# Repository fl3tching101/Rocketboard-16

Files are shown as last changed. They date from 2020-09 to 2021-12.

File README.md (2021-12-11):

# Rocketboard-16
 16 key RGB backlit macro board/numpad with two EC11 rotary encoder switches and a 128x64 OLED display
 
 <p align="center">
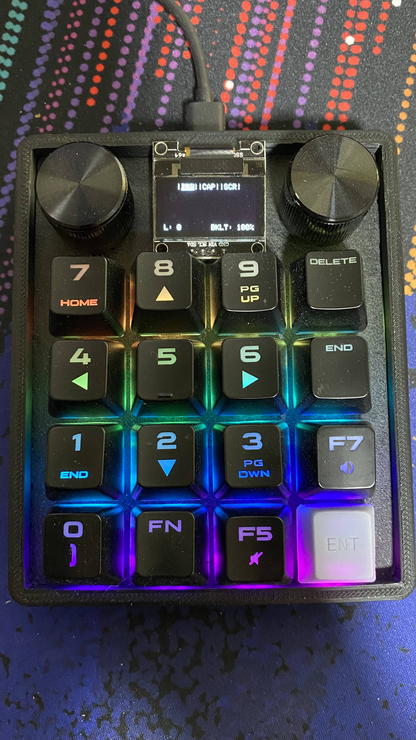
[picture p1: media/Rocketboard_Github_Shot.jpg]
 
 </p>

In addition to running [QMK](https://qmk.fm/) the Rocketboard 16 is compatible with [VIA](https://caniusevia.com/) for quick and easy configuration.
<p align="center">
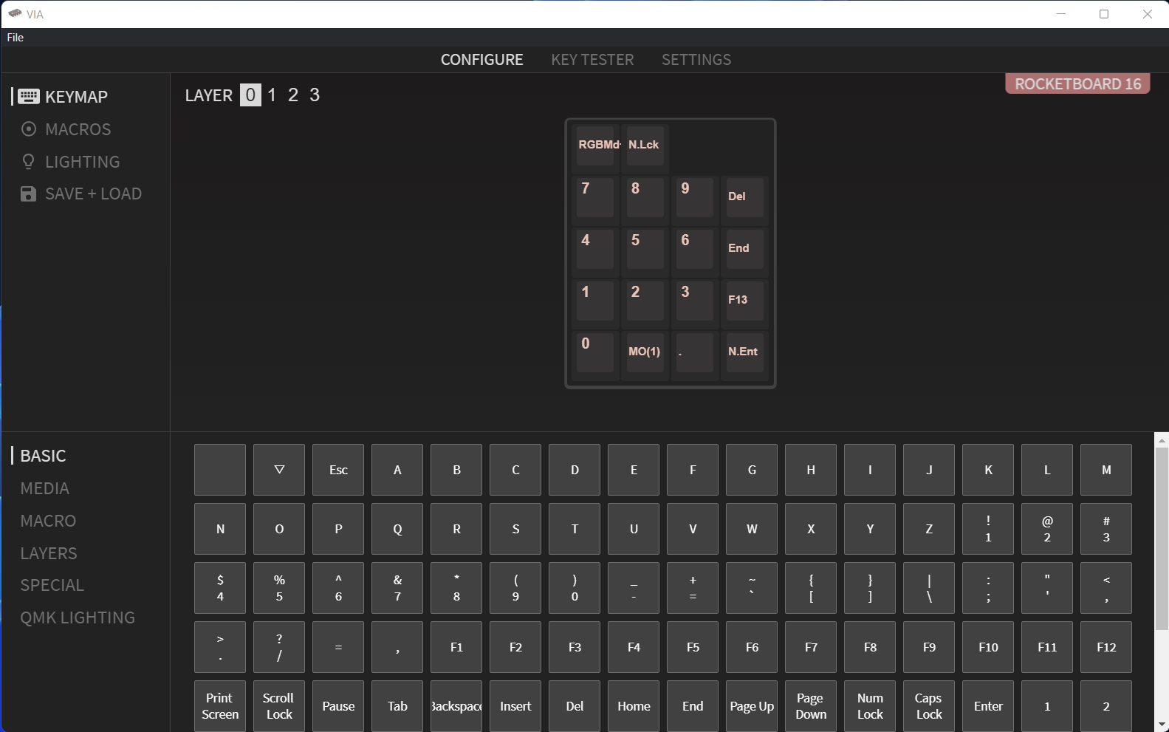
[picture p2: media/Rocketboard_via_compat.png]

</p>
 
The firmware is open source and integrated with the QMK project, it can be found [here](https://github.com/qmk/qmk_firmware/tree/master/keyboards/rocketboard_16).

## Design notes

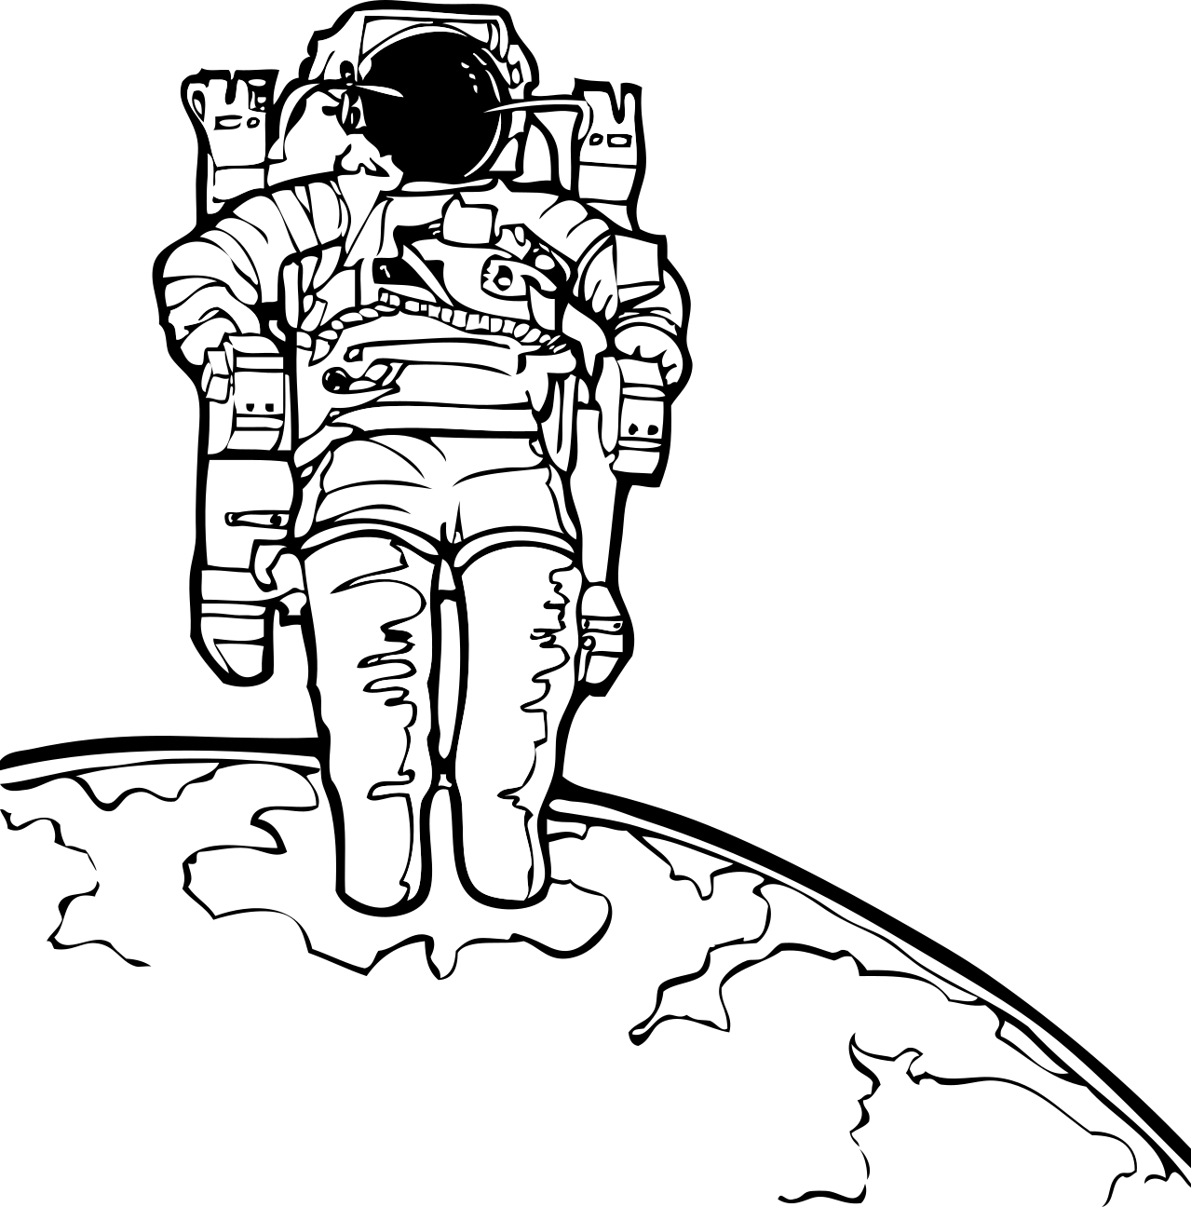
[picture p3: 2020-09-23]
graphics/spacewalk.png

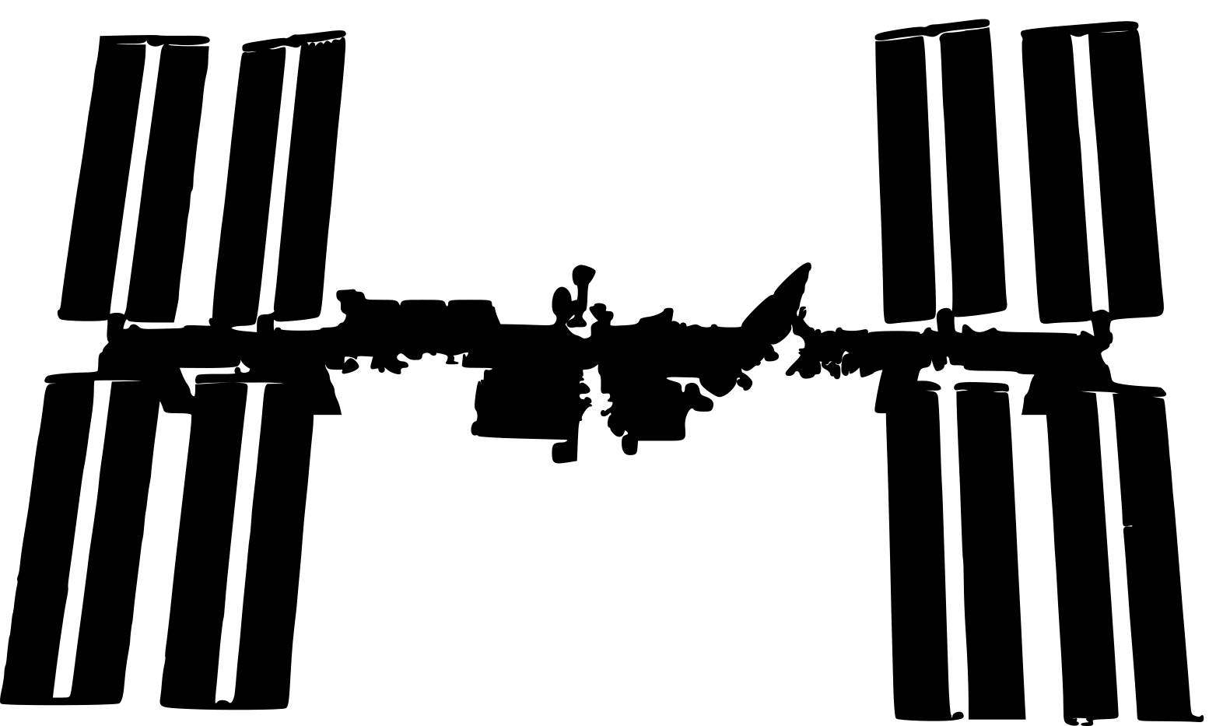
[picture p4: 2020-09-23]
graphics/ISS.png

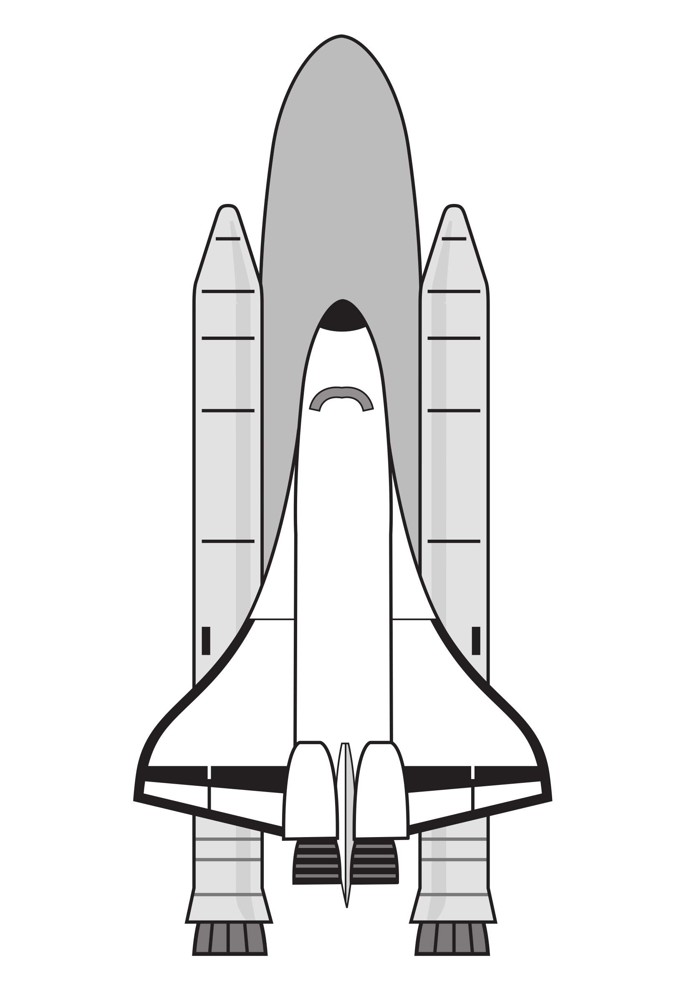
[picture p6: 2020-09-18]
graphics/space_shuttle.png

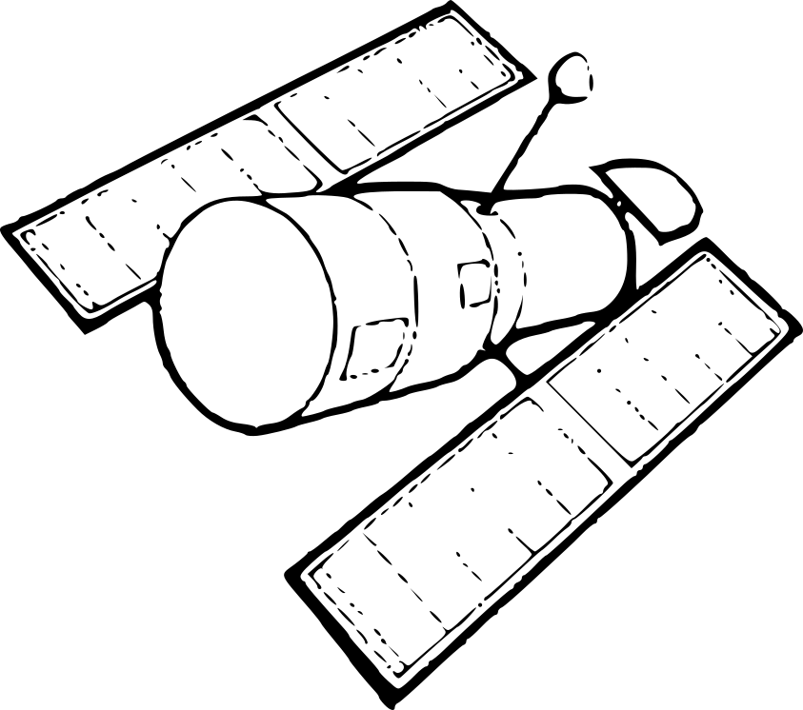
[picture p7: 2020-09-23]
graphics/Hubble_space_telescope.png

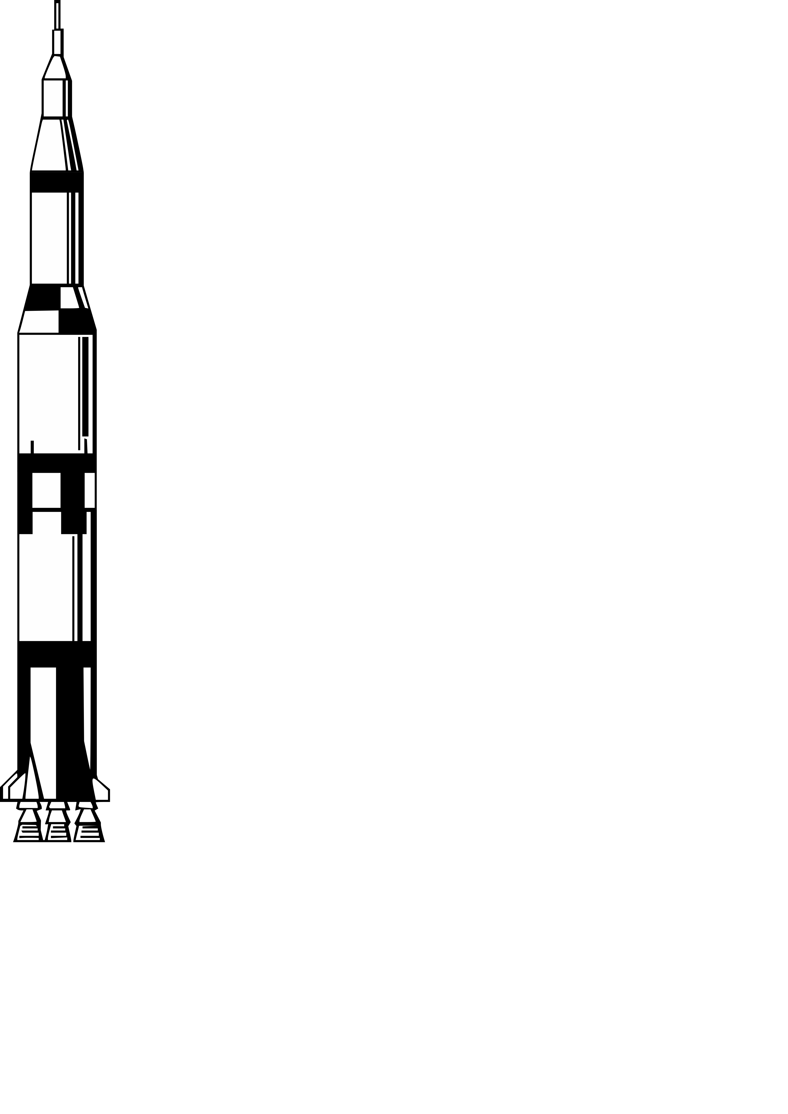
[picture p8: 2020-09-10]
graphics/saturn_v_simplified.png

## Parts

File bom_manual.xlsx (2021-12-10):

Qty | Reference(s) | Value | Footprint | MPN | Vender | Vender Part # | Manufacturer | DNP | Cost | Board Cost | Notes
2 | C1, C2 | 20p | Capacitor_SMD:C_0603_1608Metric | CL10C200JB8NNNC | JLCPCB | C1648 | Samsung Electro-Mechanics |  | $0.0085 | $0.0170
2 | C3, C12 | 10p | Capacitor_SMD:C_0603_1608Metric | CL10C100JB8NNNC | JLCPCB | C1634 | Samsung Electro-Mechanics |  | $0.0083 | $0.0166 | Only to be loaded on prototypes unless a use is found for the LSE (RTC) oscillator
27 | C4, C5, C6, C7, C8, C9, C14, C15, C16, C17, C18, C19, C20, C21, C22, C23, C24, C25, C26, C27, C28, C29, C30, C32, C33, C34, C35 | 0.1u | Capacitor_SMD:C_0603_1608Metric | CC0603KRX7R9BB104 | JLCPCB | C14663 | YAGEO |  | $0.0068 | $0.1836
1 | C10 | 1u | Capacitor_Tantalum_SMD:CP_EIA-3216-10_Kemet-I | CA45-A-16V-1uF-K | JLCPCB | C140386 | Shenzhen Zhenhua XinYun Elec |  | $0.0716 | $0.0716 | POLARIZED!!!
1 | C11 | 3.3u | Capacitor_SMD:C_0603_1608Metric | CL10A335KP8NNNC | JLCPCB | C51412 | Samsung Electro-Mechanics |  | $0.0170 | $0.0170 | Only 10v, careful!
1 | C13 | 10u | Capacitor_Tantalum_SMD:CP_EIA-3216-10_Kemet-I | TAJA106K016RNJ | JLCPCB | C7171 | AVX |  | $0.1549 | $0.1549
1 | C31 | 1u | Capacitor_SMD:C_0603_1608Metric | CL10A105KB8NNNC | JLCPCB | C15849 | Samsung Electro-Mechanics |  | $0.0129 | $0.0129
1 | C36 | 10u | Capacitor_SMD:C_0603_1608Metric | CL10A106MA8NRNC | LCSC | C96446 | Samsung Electro-Mechanics | Yes | $0.0334 | $0.0334
19 | D1, D2, D3, D4, D5, D6, D7, D8, D9, D10, D11, D12, D13, D14, D15, D16, D17, D18, D19 | D | Diode_SMD:D_SOD-123 | 1N4148W | JLCPCB | C81598 | Semtech |  | $0.0140 | $0.2660
16 | D20, D21, D22, D23, D24, D25, D26, D27, D28, D29, D30, D31, D32, D33, D34, D35 | SK6812MINI-E | seth-keyboard:DUMMY_SK6812MINI-E | YS-SK6812MINI-E | AliExpress |  | Yushakobo | Yes | $0.1049 | $1.6784 | Cannot find anywhere but AliExpress, will have to be hand soldered for the time being
4 | H1, H2, H3, H4 | Mount | MountingHole:MountingHole_3.2mm_M3 |  |  |  |  | Yes |  | $0.0000 | Nothing to be loaded
1 | H5 | Graphic | seth-logo:saturn_v_simplified |  |  |  |  |  |  | $0.0000
1 | H6 | Board Info | seth-logo:board-title |  |  |  |  |  |  | $0.0000
1 | H7 | Graphic | seth-logo:lunar_module |  |  |  |  |  |  | $0.0000
1 | H8 | Board Info | seth-logo:text |  |  |  |  |  |  | $0.0000
1 | H9 | Graphic | seth-logo:space_shuttle |  |  |  |  |  |  | $0.0000
1 | H10 | Graphic | seth-logo:iss |  |  |  |  |  |  | $0.0000
1 | H11 | Graphic | seth-logo:spacewalk |  |  |  |  |  |  | $0.0000
1 | H12 | Graphic | seth-logo:hubble_space_telescope |  |  |  |  |  |  | $0.0000
1 | J1 | SWD | Connector_PinHeader_2.54mm:PinHeader_1x04_P2.54mm_Vertical |  |  |  |  | Yes |  | $0.0000 | Will only be loaded for debugging purposes
1 | JP1 | BOOT1_JMP | Jumper:SolderJumper-3_P1.3mm_Open_Pad1.0x1.5mm |  |  |  |  | Yes |  | $0.0000 | Is only a footprint
1 | JP2 | BOOT0_JMP | Jumper:SolderJumper-3_P1.3mm_Open_Pad1.0x1.5mm |  |  |  |  | Yes |  | $0.0000 | Is only a footprint
16 | K1, K2, K3, K4, K5, K6, K7, K8, K9, K10, K11, K12, K13, K14, K15, K16 | MX_RGB | seth-keyboard:MX_KEYSWITCH_RGB_2D |  |  |  |  | Yes |  | $0.0000 | Footprint only, user will load own switch
1 | P1 | USB_C_Plug_USB2.0 | Connector_USB:USB_C_Receptacle_Palconn_UTC16-G | MC-311D | LCSC | C136423 | SOFNG | Yes | $0.8450 | $0.8450 | Not carried by JLCPCB - mounting pins may not be long enough for 1.6mm board!
1 | Q1 | BSS138 | Package_TO_SOT_SMD:SOT-23 | BSS138 | LCSC | C489349 | KEXIN |  | $0.0173 | $0.0173
2 | R1, R2 | 20 | Resistor_SMD:R_0603_1608Metric | 0603WAF200JT5E | JLCPCB | C22950 | Uniroyal Elec |  | $0.0016 | $0.0032
15 | R3, R8, R9, R10, R11, R12, R13, R14, R15, R16, R17, R18, R19, R20, R21 | 10k | Resistor_SMD:R_0603_1608Metric | 0603WAF1002T5E | JLCPCB | C25804 | Uniroyal Elec |  | $0.0020 | $0.0300
2 | R4, R5 | 5.1k | Resistor_SMD:R_0603_1608Metric | 0603WAF5101T5E | JLCPCB | C23186 | Uniroyal Elec |  | $0.0019 | $0.0038
1 | R6 | 1.5k | Resistor_SMD:R_0603_1608Metric | 0603WAF1501T5E | JLCPCB | C22843 | Uniroyal Elec |  | $0.0018 | $0.0018
1 | R7 | 1k | Resistor_SMD:R_0603_1608Metric | 0603WAF1001T5E | JLCPCB | C21190 | Uniroyal Elec |  | $0.0021 | $0.0021
1 | SW1 | SW_Push | Button_Switch_SMD:SW_Push_1P1T_NO_6x6mm_H9.5mm | TS-1187A-C-C-B | JLCPCB | C318889 | XKB Enterprise |  | $0.0348 | $0.0348
1 | SW2 | Rotary 1 | seth-buttons:RotaryEncoder_Alps_EC11E-Switch_Vertical_H20mm_CircularMountingHoles | EC11E1534408 | LCSC | C278348 | ALPS Electric | Yes | $1.9433 | $1.9433
1 | SW3 | Rotary 2 | seth-buttons:RotaryEncoder_Alps_EC11E-Switch_Vertical_H20mm_CircularMountingHoles | EC11E1534408 | LCSC | C278348 | ALPS Electric | Yes | $1.9433 | $1.9433
1 | U1 | STM32F103C8T6 | Package_QFP:LQFP-48_7x7mm_P0.5mm | STM32F103C8T6 | JLCPCB | C8734 | STMicroelectronics |  | $1.4413 | $1.4413
1 | U2 | AMS1117-3.3 | Package_TO_SOT_SMD:SOT-223-3_TabPin2 | AMS1117-3.3 | JLCPCB | C6186 | Advanced Monolithic Systems |  | $0.1240 | $0.1240
1 | U3 | USBLC6-2SC6 | Package_TO_SOT_SMD:SOT-23-6 | USBLC6-2SC6 | JLCPCB | C7519 | STMicroelectronics |  | $0.0915 | $0.0915
1 | U4 | SSD1306_128x64 | Connector_PinHeader_2.54mm:PinHeader_1x04_P2.54mm_Vertical | MTF185-104SY1 | LCSC | C358718 | MINTRON | Yes | $0.0550 | $0.0550
1 | X1 | 8 MHz | Crystal:Crystal_SMD_5032-4Pin_5.0x3.2mm | X50328MSB4SI | JLCPCB | C157341 | Yangxing Tech |  | $0.2187 | $0.2187
1 | Y1 | 32.768 kHz | Crystal:Crystal_SMD_3215-2Pin_3.2x1.5mm | Q13FC1350000200 | JLCPCB | C48615 | Seiko Epson |  | $0.2336 | $0.2336 | Only to be loaded on prototypes unless a use is found for the LSE (RTC) oscillator
 |  |  |  |  |  |  | Unique parts (loaded) count: |  |  | JLCPCB Cost:
 |  |  |  |  |  |  | 28 |  |  | $2.9417
 |  |  |  |  |  |  | Number of loaded SMD parts: |  |  | Other Cost:
 |  |  |  |  |  |  | 90 |  |  | $6.4984
 |  |  |  |  |  |  | Number of parts: |  |  | Total Cost:
 |  |  |  |  |  |  | 134 |  |  | $9.4401
 | Alternates:
1 | U2 | AMS1117-3.3 | Package_TO_SOT_SMD:SOT-223-3_TabPin2 | AMS1117-3.3 | JLCPCB | C347222 | UMW(Youtai Semiconductor Co., Ltd.) |  | $0.1240 | $0.1240
1 | Y1 | 32.768 kHz | Crystal:Crystal_SMD_3215-2Pin_3.2x1.5mm | X1A000141000100 | JLCPCB | C94674 | Seiko Epson |  | $0.2336 | $0.2336 | Only to be loaded on prototypes unless a use is found for the LSE (RTC) oscillator
27 | C4, C5, C6, C7, C8, C9, C14, C15, C16, C17, C18, C19, C20, C21, C22, C23, C24, C25, C26, C27, C28, C29, C30, C32, C33, C34, C35 | 0.1u | Capacitor_SMD:C_0603_1608Metric | FN18F104Z500PSG | JLCPCB | C497032 | PSA(Prosperity Dielectrics) |  | $0.0030 | $0.0813

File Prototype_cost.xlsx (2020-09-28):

Vender | Description | Cost | Notes
Aliexpress | SK6812Mini-E RGB LEDs x 100 | $11.2800 | Not able to find these anywhere else, shipping is slow Aliexpress value shipping
u/tonsoffun | Mill-Max 0305-2-15-80-47-80-10 x 200 | $25.0000 | Cheaper than Mouser order, $18 + $7 shipping
JLCPCB | PCB + Stencil | $34.9100 | Went with FedEx International for about $10 less shipping
LCSC | Parts (see LCSC BOM) | $59.8500 | Saved $15 on shipping with a first order coupon
Amazon | SSD1306 128x64 OLED Display x 6 | $33.3200 | Bought 4 blue PCBs and 2 black PCBs, both white pixels
 | Rotary encoder knobs
 | Total: | $164.3600

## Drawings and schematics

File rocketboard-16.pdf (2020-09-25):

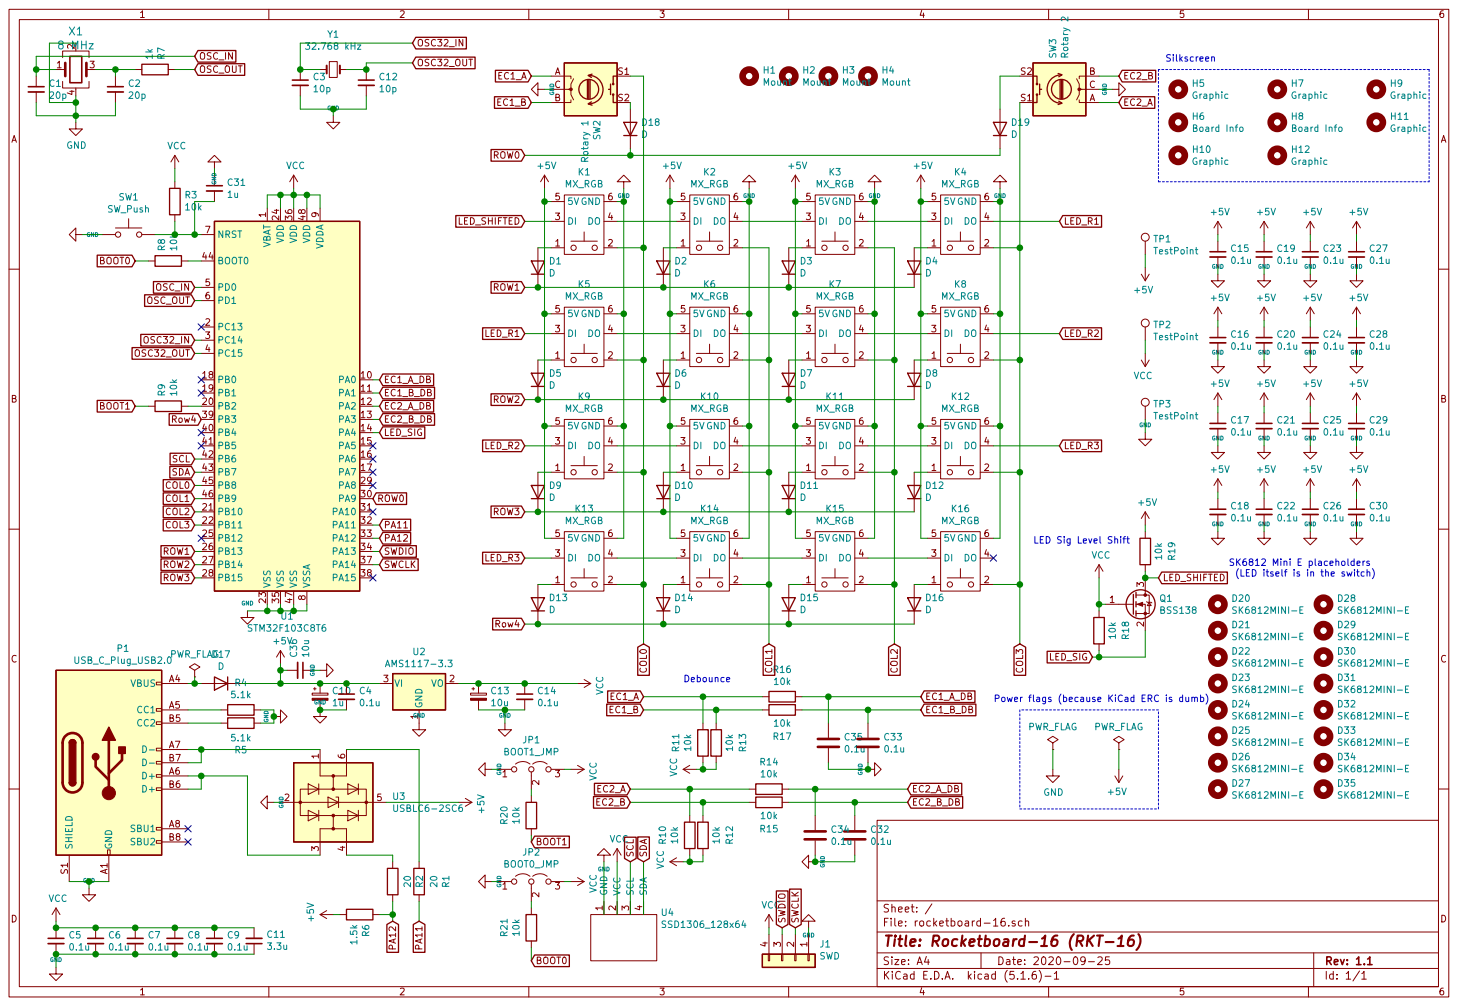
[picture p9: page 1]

1 VDD 24 VDD 36 VDD 48 VDDA

9 VSS 23 VSS 35 VSS 47 VSSA

Id: 1/1 Title: Rocketboard-16 (RKT-16) File: rocketboard-16.sch Sheet: / R810k

LED Sig Level Shift

SK6812 Mini E placeholders
(LED itself is in the switch)

4U4SSD1306_128x64 D22 SK6812MINI-E D21 SK6812MINI-E GND GND VCC VCC

Power flags (because KiCad ERC is dumb) Debounce

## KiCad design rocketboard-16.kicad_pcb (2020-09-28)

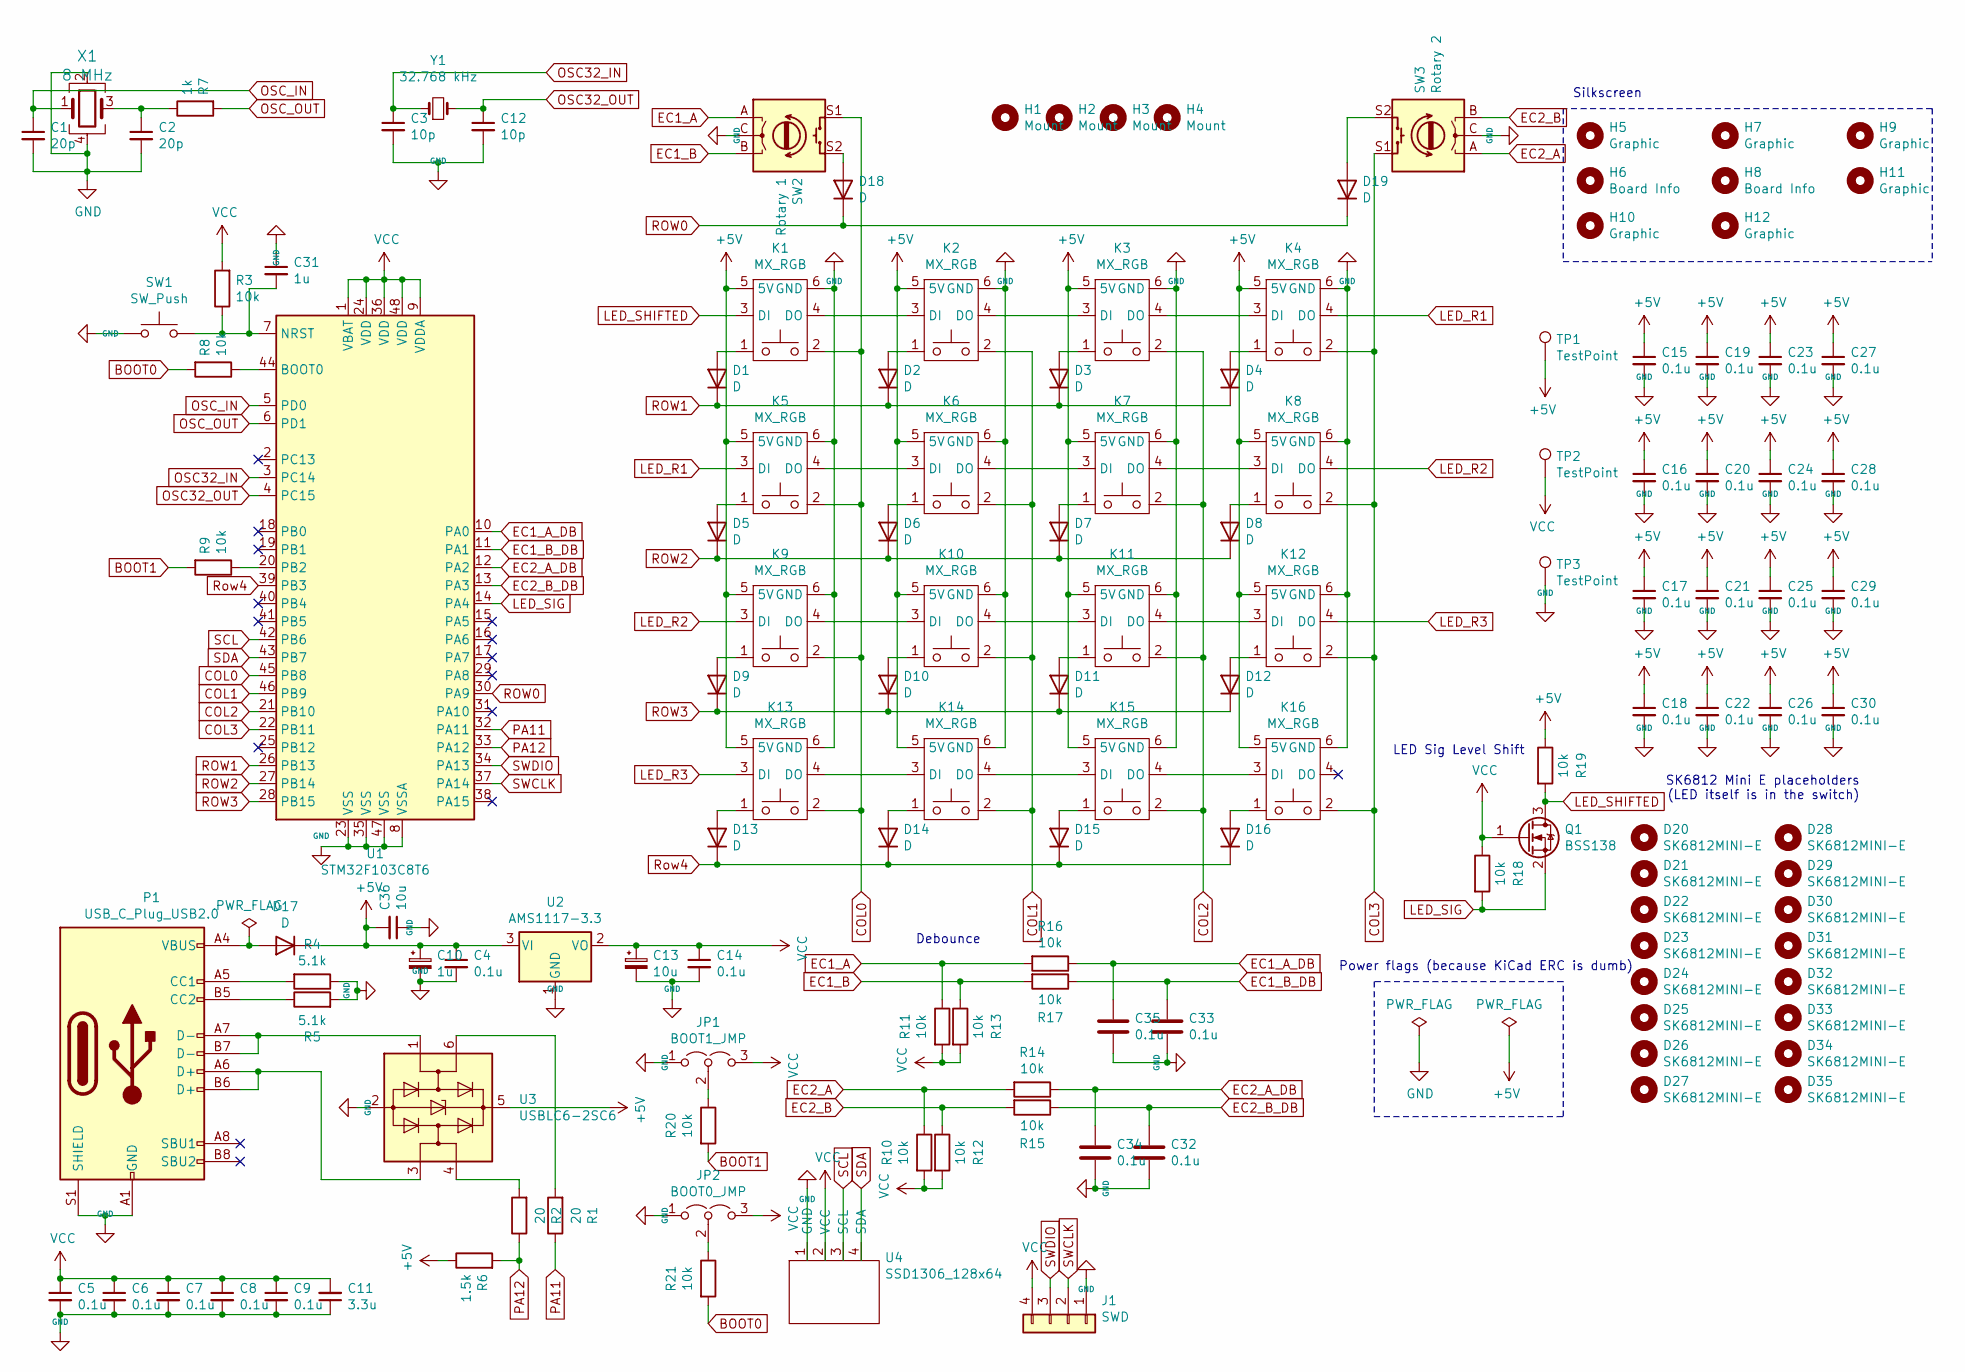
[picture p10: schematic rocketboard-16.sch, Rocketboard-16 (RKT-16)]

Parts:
C1, C2: 20p; C_0603_1608Metric
C3, C12: 10p; C_0603_1608Metric
C4, C5, C6, C7, C8, C9, C14, C15, C16, C17, C18, C19, C20, C21, C22, C23, C24, C25, C26, C27, C28, C29, C30, C32, C33, C34, C35: 0.1u; C_0603_1608Metric
C10: 1u; CP_EIA-3216-10_Kemet-I
C11: 3.3u; C_0603_1608Metric
C13: 10u; CP_EIA-3216-10_Kemet-I
C31: 1u; C_0603_1608Metric
C36: 10u; C_0603_1608Metric
D1, D2, D3, D4, D5, D6, D7, D8, D9, D10, D11, D12, D13, D14, D15, D16, D17, D18, D19: D; D_SOD-123
D20, D21, D22, D23, D24, D25, D26, D27, D28, D29, D30, D31, D32, D33, D34, D35: SK6812MINI-E; DUMMY_SK6812MINI-E
H1, H2, H3, H4: Mount; MountingHole_3.2mm_M3
H5: Graphic; saturn_v_simplified
H6: Board Info; board-title
H7: Graphic; lunar_module
H8: Board Info; text
H9: Graphic; space_shuttle
H10: Graphic; iss
H11: Graphic; spacewalk
H12: Graphic; hubble_space_telescope
J1: SWD; PinHeader_1x04_P2.54mm_Vertical
JP1: BOOT1_JMP; SolderJumper-3_P1.3mm_Open_Pad1.0x1.5mm
JP2: BOOT0_JMP; SolderJumper-3_P1.3mm_Open_Pad1.0x1.5mm
K1, K2, K3, K4, K5, K6, K7, K8, K9, K10, K11, K12, K13, K14, K15, K16: MX_RGB; MX_KEYSWITCH_RGB_2D
P1: USB_C_Plug_USB2.0; USB_C_Receptacle_Palconn_UTC16-G
Q1: BSS138; SOT-23
R1, R2: 20; R_0603_1608Metric
R3, R8, R9, R10, R11, R12, R13, R14, R15, R16, R17, R18, R19, R20, R21: 10k; R_0603_1608Metric
R4, R5: 5.1k; R_0603_1608Metric
R6: 1.5k; R_0603_1608Metric
R7: 1k; R_0603_1608Metric
SW1: SW_Push; SW_TS-1187A-B-A-B
SW2: Rotary 1; RotaryEncoder_Alps_EC11E-Switch_Vertical_H20mm_CircularMoun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
SW3: Rotary 2; RotaryEncoder_Alps_EC11E-Switch_Vertical_H20mm_CircularMoun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
TP1, TP2, TP3: TestPoint; TestPoint_Pad_D1.0mm
U1: STM32F103C8T6; LQFP-48_7x7mm_P0.5mm
U2: AMS1117-3.3; SOT-223-3_TabPin2
U3: USBLC6-2SC6; SOT-23-6
U4: SSD1306_128x64; PinHeader_1x04_P2.54mm_Vertical
X1: 8 MHz; Crystal_SMD_5032-4Pin_5.0x3.2mm; Part_num X50328MSB4SI
Y1: 32.768 kHz; Crystal_SMD_3215-2Pin_3.2x1.5mm

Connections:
+5V: C4.1, C10.1, C15.1, C16.1, C17.1, C18.1, C19.1, C20.1, C21.1, C22.1, C23.1, C24.1, C25.1, C26.1, C27.1, C28.1, C29.1, C30.1, C36.2, D17.1 (K), K1.5 (5V), K2.5 (5V), K3.5 (5V), K4.5 (5V), K5.5 (5V), K6.5 (5V), K7.5 (5V), K8.5 (5V), K9.5 (5V), K10.5 (5V), K11.5 (5V), K12.5 (5V), K13.5 (5V), K14.5 (5V), K15.5 (5V), K16.5 (5V), R6.1, R19.1, TP1.1, U2.3 (VI), U3.5 (VBUS)
BOOT0: R8.2, R21.2
BOOT1: R9.2, R20.2
COL0: K1.2, K5.2, K9.2, K13.2, SW2.S1, U1.45 (PB8)
COL1: K2.2, K6.2, K10.2, K14.2, U1.46 (PB9)
COL2: K3.2, K7.2, K11.2, K15.2, U1.21 (PB10)
COL3: K4.2, K8.2, K12.2, K16.2, SW3.S1, U1.22 (PB11)
EC1_A: R11.1, R16.2, SW2.A
EC1_A_DB: C35.1, R16.1, U1.10 (PA0)
EC1_B: R13.1, R17.2, SW2.B
EC1_B_DB: C33.1, R17.1, U1.11 (PA1)
EC2_A: R10.1, R14.2, SW3.A
EC2_A_DB: C34.1, R14.1, U1.12 (PA2)
EC2_B: R12.1, R15.2, SW3.B
EC2_B_DB: C32.1, R15.1, U1.13 (PA3)
GND: C1.2, C2.2, C3.2, C4.2, C5.2, C6.2, C7.2, C8.2, C9.2, C10.2, C11.1, C12.2, C13.2, C14.2, C15.2, C16.2, C17.2, C18.2, C19.2, C20.2, C21.2, C22.2, C23.2, C24.2, C25.2, C26.2, C27.2, C28.2, C29.2, C30.2, C31.1, C32.2, C33.2, C34.2, C35.2, C36.1, J1.1, JP1.1 (A), JP2.1 (A), K1.6 (GND), K2.6 (GND), K3.6 (GND), K4.6 (GND), K5.6 (GND), K6.6 (GND), K7.6 (GND), K8.6 (GND), K9.6 (GND), K10.6 (GND), K11.6 (GND), K12.6 (GND), K13.6 (GND), K14.6 (GND), K15.6 (GND), K16.6 (GND), P1.A1 (GND), P1.A12 (GND), P1.B1 (GND), P1.B12 (GND), P1.S1 (SHIELD), R4.1, R5.2, SW1.1, SW2.C, SW3.C, TP3.1, U1.8 (VSSA), U1.23 (VSS), U1.35 (VSS), U1.47 (VSS), U2.1 (GND), U3.2 (GND), U4.1 (GND), X1.2, X1.4
LED_R1: K4.4 (DO), K5.3 (DI)
LED_R2: K8.4 (DO), K9.3 (DI)
LED_R3: K12.4 (DO), K13.3 (DI)
LED_SHIFTED: K1.3 (DI), Q1.3 (D), R19.2
LED_SIG: Q1.2 (S), R18.2, U1.14 (PA4)
unnamed: C2.1, R7.1, X1.3
unnamed: C31.2, R3.1, SW1.2, U1.7 (NRST)
unnamed: D1.2 (A), K1.1
unnamed: D2.2 (A), K2.1
unnamed: D3.2 (A), K3.1
unnamed: D4.2 (A), K4.1
unnamed: D5.2 (A), K5.1
unnamed: D6.2 (A), K6.1
unnamed: D7.2 (A), K7.1
unnamed: D8.2 (A), K8.1
unnamed: D9.2 (A), K9.1
unnamed: D10.2 (A), K10.1
unnamed: D11.2 (A), K11.1
unnamed: D12.2 (A), K12.1
unnamed: D13.2 (A), K13.1
unnamed: D14.2 (A), K14.1
unnamed: D15.2 (A), K15.1
unnamed: D16.2 (A), K16.1
unnamed: D17.2 (A), P1.A4 (VBUS), P1.A9 (VBUS), P1.B4 (VBUS), P1.B9 (VBUS)
unnamed: D18.2 (A), SW2.S2
unnamed: D19.2 (A), SW3.S2
unnamed: JP1.2 (C), R20.1
unnamed: JP2.2 (C), R21.1
unnamed: K1.4 (DO), K2.3 (DI)
unnamed: K2.4 (DO), K3.3 (DI)
unnamed: K3.4 (DO), K4.3 (DI)
unnamed: K5.4 (DO), K6.3 (DI)
unnamed: K6.4 (DO), K7.3 (DI)
unnamed: K7.4 (DO), K8.3 (DI)
unnamed: K9.4 (DO), K10.3 (DI)
unnamed: K10.4 (DO), K11.3 (DI)
unnamed: K11.4 (DO), K12.3 (DI)
unnamed: K13.4 (DO), K14.3 (DI)
unnamed: K14.4 (DO), K15.3 (DI)
unnamed: K15.4 (DO), K16.3 (DI)
unnamed: P1.A5 (CC1), R4.2
unnamed: P1.A6 (D+), P1.B6 (D+), U3.3 (I/O2)
unnamed: P1.A7 (D-), P1.B7 (D-), U3.1 (I/O1)
unnamed: P1.B5 (CC2), R5.1
unnamed: R1.2, U3.6 (I/O1)
unnamed: R2.2, U3.4 (I/O2)
unnamed: R8.1, U1.44 (BOOT0)
unnamed: R9.1, U1.20 (PB2)
OSC32_IN: C3.1, U1.3 (PC14), Y1.1
OSC32_OUT: C12.1, U1.4 (PC15), Y1.2
OSC_IN: C1.1, U1.5 (PD0), X1.1
OSC_OUT: R7.2, U1.6 (PD1)
PA11: R1.1, U1.32 (PA11)
PA12: R2.1, R6.2, U1.33 (PA12)
ROW0: D18.1 (K), D19.1 (K), U1.30 (PA9)
ROW1: D1.1 (K), D2.1 (K), D3.1 (K), D4.1 (K), U1.26 (PB13)
ROW2: D5.1 (K), D6.1 (K), D7.1 (K), D8.1 (K), U1.27 (PB14)
ROW3: D9.1 (K), D10.1 (K), D11.1 (K), D12.1 (K), U1.28 (PB15)
Row4: D13.1 (K), D14.1 (K), D15.1 (K), D16.1 (K), U1.39 (PB3)
SCL: U1.42 (PB6), U4.3 (SCL)
SDA: U1.43 (PB7), U4.4 (SDA)
SWCLK: J1.2, U1.37 (PA14)
SWDIO: J1.3, U1.34 (PA13)
VCC: C5.1, C6.1, C7.1, C8.1, C9.1, C11.2, C13.1, C14.1, J1.4, JP1.3 (B), JP2.3 (B), Q1.1 (G), R3.2, R10.2, R11.2, R12.2, R13.2, R18.1, TP2.1, U1.1 (VBAT), U1.9 (VDDA), U1.24 (VDD), U1.36 (VDD), U1.48 (VDD), U2.2 (VO), U4.2 (VCC)

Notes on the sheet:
SK6812 Mini E placeholders (LED itself is in the switch)
Power flags (because KiCad ERC is dumb)
Silkscreen
Debounce
LED Sig Level Shift

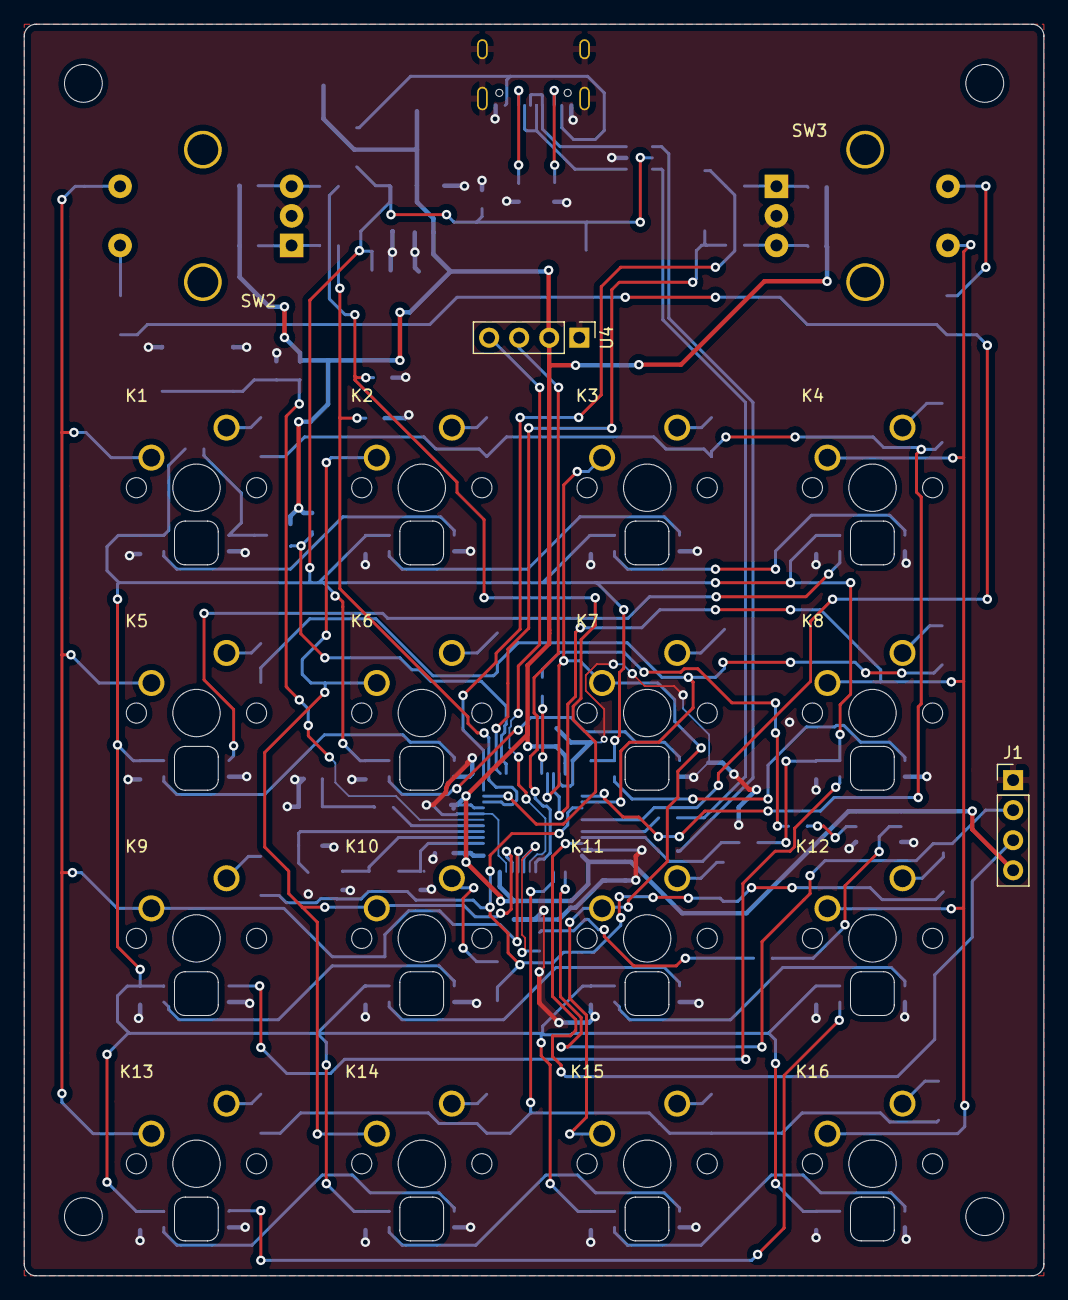
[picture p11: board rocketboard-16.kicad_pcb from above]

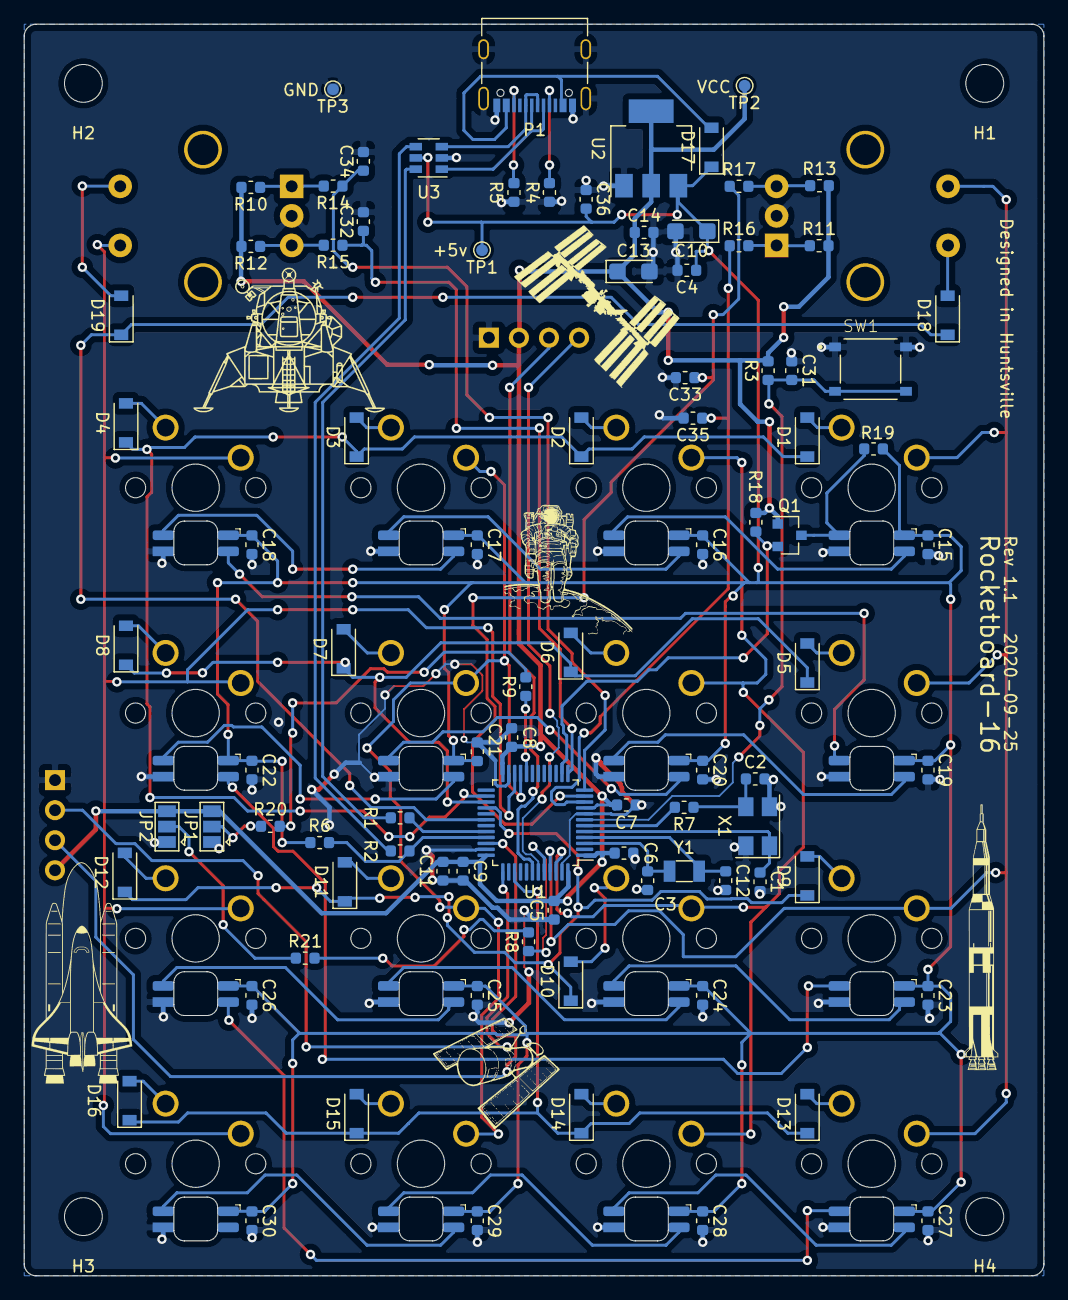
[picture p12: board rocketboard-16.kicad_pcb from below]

Board: 2 copper layers, 86.2 x 105.8 mm, 137 parts (117 on the bottom side), 80 nets.

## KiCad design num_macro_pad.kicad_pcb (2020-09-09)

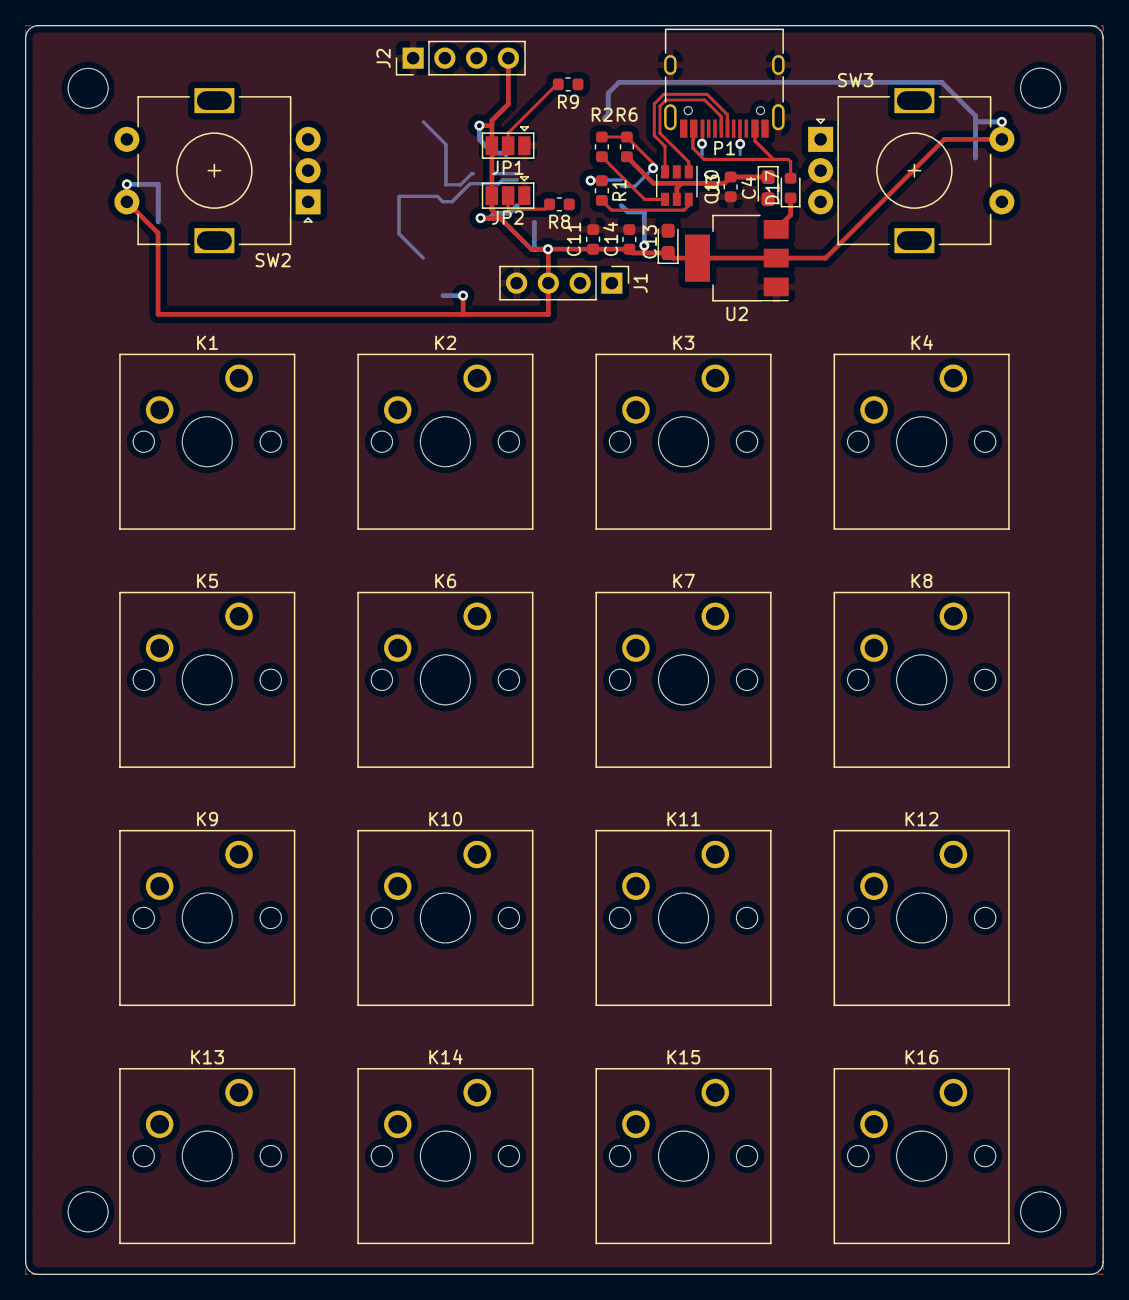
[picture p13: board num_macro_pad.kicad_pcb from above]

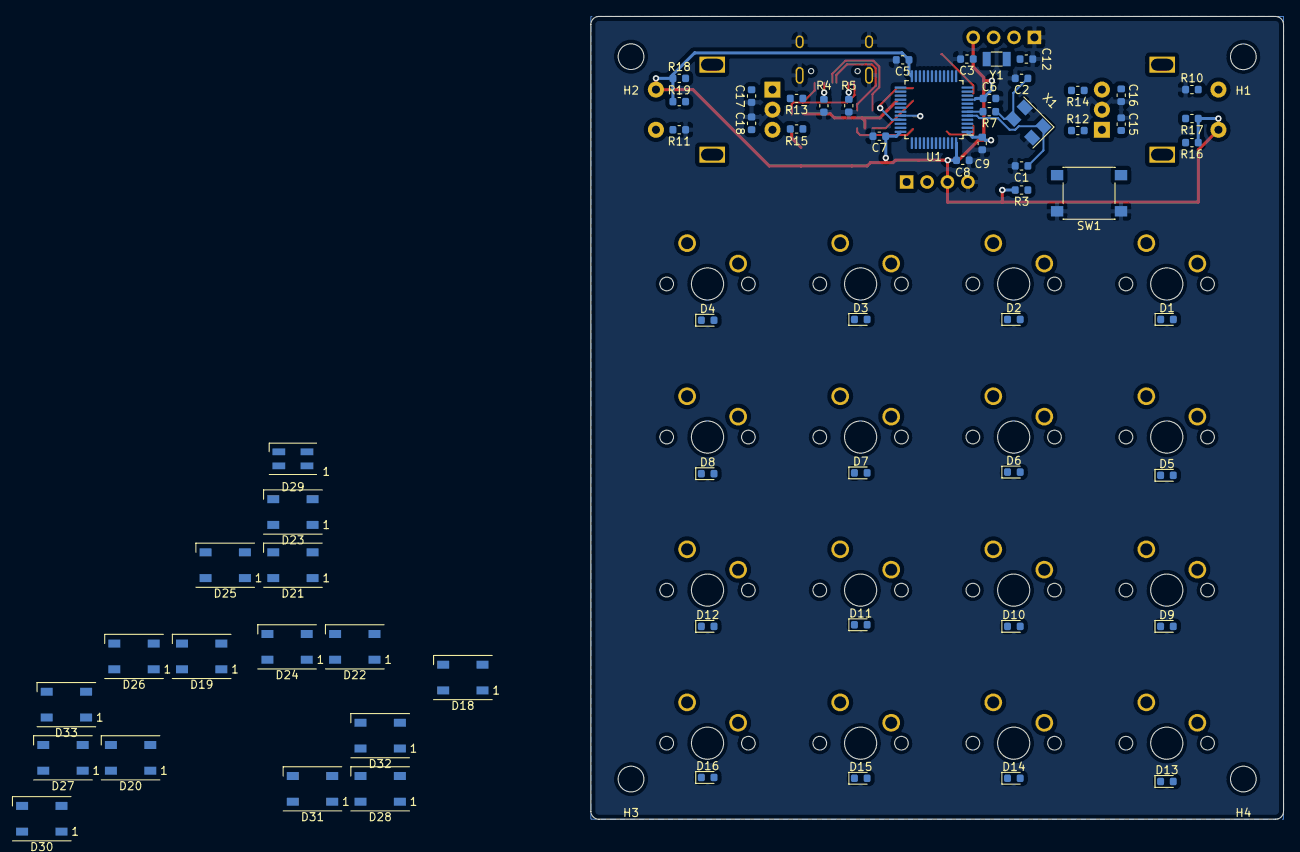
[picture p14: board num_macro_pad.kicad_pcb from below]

Board: 2 copper layers, 86.2 x 99.9 mm, 103 parts (67 on the bottom side), 76 nets.

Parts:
C1, C2: 27p; C_0603_1608Metric
C3, C12: 12.5p; C_0603_1608Metric
C4: 0.1u; CP_EIA-2012-12_Kemet-R
C5, C6, C7, C8, C9, C14, C15, C16, C17, C18: 0.1u; C_0603_1608Metric
C10: 1u; C_0603_1608Metric
C11: 3.3u; C_0603_1608Metric
C13: 10u; CP_EIA-2012-12_Kemet-R
D1, D2, D3, D4, D5, D6, D7, D8, D9, D10, D11, D12, D13, D14, D15, D16, D17: D; D_0603_1608Metric
D18, D19, D20, D21, D22, D23, D24, D25, D26, D27, D28, D30, D31, D32, D33: WS2812B; LED_WS2812B_PLCC4_5.0x5.0mm_P3.2mm
D29: LED_SK6812MINI_PLCC4_3.5x3.5mm_P1.75mm
H1, H2, H3, H4: Mount; MountingHole_3.2mm_M3
J1: OLED; PinHeader_1x04_P2.54mm_Vertical
J2: SWD; PinHeader_1x04_P2.54mm_Vertical
JP1: BOOT1_JMP; SolderJumper-3_P1.3mm_Open_Pad1.0x1.5mm
JP2: BOOT0_JMP; SolderJumper-3_P1.3mm_Open_Pad1.0x1.5mm
K1, K2, K3, K4, K5, K6, K7, K8, K9, K10, K11, K12, K13, K14, K15, K16: KEYSW; SW_Cherry_MX_1.00u_PCB
P1: USB_C_Plug_USB2.0; USB_C_Receptacle_HRO_TYPE-C-31-M-12
R1, R2, R3: 20; R_0603_1608Metric
R4, R5: 5.1k; R_0603_1608Metric
R6: 1.5k; R_0603_1608Metric
R7: 390; R_0603_1608Metric
R8, R9, R10, R11, R12, R13, R14, R15, R16, R17, R18, R19: 10k; R_0603_1608Metric
SW1: SW_Push; SW_Push_1P1T_NO_6x6mm_H9.5mm
SW2: Rotary 1; RotaryEncoder_Alps_EC11E-Switch_Vertical_H20mm
SW3: Rotary 2; RotaryEncoder_Alps_EC11E-Switch_Vertical_H20mm
U1: STM32F103C8T6; LQFP-48_7x7mm_P0.5mm
U2: AMS1117-3.3; SOT-223-3_TabPin2
U3: USBLC6-2SC6; SOT-23-6
X1: 8 MHz; Crystal_SMD_5032-4Pin_5.0x3.2mm
Y1: 32.768 kHz; Crystal_SMD_3215-2Pin_3.2x1.5mm

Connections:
+5V: C4.1, C10.1, D17.1, D18.1, D19.1, D20.1, D21.1, D22.1, D23.1, D24.1, D25.1, D26.1, D27.1, D28.1, D29.1, D30.1, D31.1, D32.1, D33.1, R6.1, U2.3, U3.5
BOOT0: JP2.2, R8.2
BOOT1: JP1.2, R9.2
COL0: K1.1, K5.1, K9.1, K13.1, U1.45
COL1: K2.1, K6.1, K10.1, K14.1, U1.46
COL2: K3.1, K7.1, K11.1, K15.1, U1.21
COL3: K4.1, K8.1, K12.1, K16.1, U1.22
EC1_A: R12.2, U1.10
EC1_B: R14.1, U1.11
EC1_S1: R10.2, SW2.S1, U1.13
EC2_A: R13.2, U1.16
EC2_B: R15.1, U1.17
EC2_S1: R11.2, SW3.S1, U1.14
GND: C1.2, C2.2, C3.2, C4.2, C5.2, C6.2, C7.2, C8.2, C9.2, C10.2, C11.1, C12.2, C13.2, C14.2, C15.1, C16.2, C17.1, C18.2, D18.3, D19.3, D20.3, D21.3, D22.3, D23.3, D24.3, D25.3, D26.3, D27.3, D28.3, D29.3, D30.3, D31.3, D32.3, D33.3, J1.4, J2.1, JP1.1, JP2.1, P1.A1, P1.A12, P1.B1, P1.B12, P1.S1, R4.1, R5.1, R10.1, R11.1, SW1.1, SW2.C, SW3.C, U1.8, U1.23, U1.35, U1.47, U2.1, U3.2, X1.2, X1.4
LED_SIG: D18.4, U1.12
unnamed: C2.1, R7.1, X1.3
unnamed: C15.2, R12.1, R16.2, SW2.A
unnamed: C16.1, R14.2, R17.2, SW2.B
unnamed: C17.2, R13.1, R18.2, SW3.A
unnamed: C18.1, R15.2, R19.2, SW3.B
unnamed: D1.2, K1.2
unnamed: D2.2, K2.2
unnamed: D3.2, K3.2
unnamed: D4.2, K4.2
unnamed: D5.2, K5.2
unnamed: D6.2, K6.2
unnamed: D7.2, K7.2
unnamed: D8.2, K8.2
unnamed: D9.2, K9.2
unnamed: D10.2, K10.2
unnamed: D11.2, K11.2
unnamed: D12.2, K12.2
unnamed: D13.2, K13.2
unnamed: D14.2, K14.2
unnamed: D15.2, K15.2
unnamed: D16.2, K16.2
unnamed: D17.2, P1.A4, P1.A9, P1.B4, P1.B9
unnamed: D18.2, D22.4
unnamed: D19.2, D20.4
unnamed: D19.4, D23.2
unnamed: D20.2, D24.4
unnamed: D21.4, D25.2
unnamed: D22.2, D26.4
unnamed: D23.4, D27.2
unnamed: D24.2, D28.4
unnamed: D25.4, D29.2
unnamed: D26.2, D30.4
unnamed: D27.4, D31.2
unnamed: D28.2, D32.4
unnamed: D29.4, D33.2
unnamed: D30.2, D31.4
unnamed: D32.2, D33.4
unnamed: P1.A5, R4.2
unnamed: P1.A6, U3.3
unnamed: P1.A7, U3.1
unnamed: P1.B5, R5.2
unnamed: R1.2, U3.6
unnamed: R2.2, U3.4
unnamed: R3.1, SW1.2, U1.7
unnamed: R8.1, U1.44
unnamed: R9.1, U1.20
OSC32_IN: C3.1, U1.3, Y1.1
OSC32_OUT: C12.1, U1.4, Y1.2
OSC_IN: C1.1, U1.5, X1.1
OSC_OUT: R7.2, U1.6
PA11: R1.1, U1.32
PA12: R2.1, R6.2, U1.33
ROW0: D1.1, D2.1, D3.1, D4.1, U1.25
ROW1: D5.1, D6.1, D7.1, D8.1, U1.26
ROW2: D9.1, D10.1, D11.1, D12.1, U1.27
ROW3: D13.1, D14.1, D15.1, D16.1, U1.28
SCL: J1.2, U1.42
SDA: J1.1, U1.43
SWCLK: J2.2, U1.37
SWDIO: J2.3, U1.34
VCC: C5.1, C6.1, C7.1, C8.1, C9.1, C11.2, C13.1, C14.1, J1.3, J2.4, JP1.3, JP2.3, R3.2, R16.1, R17.1, R18.1, R19.1, SW2.S2, SW3.S2, U1.1, U1.9, U1.24, U1.36, U1.48, U2.2

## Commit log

2020-09-09 Initial commit - bad routing and bad backlighting
    Backup of bad version before I begin fixing
    [num_macro_pad.kicad_pcb, num_macro_pad.sch]
2020-09-09 Fixed the schematic issues (replaced keyswitch symbol for RGB LED, removed old LEDs, replaced USB-C connector), and moved those changes to PCBNew, but have not put all components onto board yet.
    [num_macro_pad.sch, rocketboard-16.kicad_pcb, rocketboard-16.sch]
2020-09-10 Placed all componenets onto PCB and added josh's 3D model library in to get better 3D previews
    [rocketboard-16.kicad_pcb, rocketboard-16.sch]
2020-09-10 Fixed some of the 3D model references, added a symbol/footprint for the SSD1306 OLED display with a 3D model for pictures, and added draft logo with board info
    [rocketboard-16.kicad_pcb, rocketboard-16.sch]
2020-09-11 Extended PCB height to accomodate the OLED display. Changed the board color to black for previews. Moved components up to take up new space from increasing height of board.
    [rocketboard-16.kicad_pcb]
2020-09-11 Routed the two crystals
    [rocketboard-16.kicad_pcb]
2020-09-12 Routed most of the wires, many still needed though. Changed a couple of pins around on the schematic due to simpler routing paths.
    [rocketboard-16.kicad_pcb, rocketboard-16.sch]
2020-09-13 Routed more traces. Only lacking a few more connections except for ground. Had to move some pins around to make room, though the change did not help with routing so far.
    [rocketboard-16.kicad_pcb, rocketboard-16.sch]
2020-09-14 Finished all routing, very messy, but theoretically should work
    [rocketboard-16.kicad_pcb]
2020-09-14 Generated the gerber files, placed in a folder, and zipped them for uploading. Also had to regenerate the fill.
    [rocketboard-16-B_Cu.gbr, rocketboard-16-B_Mask.gbr, rocketboard-16-B_Paste.gbr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]
2020-09-15 Updated symbols and footprints to use project specific files (portability). Changed one via, was only one smaller than rest.
    [rocketboard-16-B_Cu.gbr, rocketboard-16-B_Mask.gbr, rocketboard-16-B_Paste.gbr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]
2020-09-15 Updated schematic and pcb as I found specific parts for BOM, now board needs routing for the diodes on the switches. Created a BOM spreadsheet for manual entry of part numbers, venders, prices, etc.
    [bom_manual.xlsx, rocketboard-16.kicad_pcb, rocketboard-16.sch]
2020-09-16 Finished adding items to the BOM, added a tactile switch from JLCPCB footprint instead of the one I had
    [bom_manual.xlsx, rocketboard-16.kicad_pcb, rocketboard-16.sch]
2020-09-16 Connected up all the components that changed due to BOM items. Still has one missing fill connection for some reason.
    [rocketboard-16.kicad_pcb]
2020-09-18 Updated the graphics, added some more, and made some slight changed to some components
    [bom_manual.xlsx, rocketboard-16.kicad_pcb, rocketboard-16.sch]
2020-09-18 Regenerated the gerber files
    [rocketboard-16-B_Cu.gbr, rocketboard-16-B_Mask.gbr, rocketboard-16-B_Paste.gbr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]
2020-09-18 Plotted schematic
2020-09-19 Needed to add debounce and pullups to the rotary encoder lines, added to sch and updated PCB
    [rocketboard-16.kicad_pcb, rocketboard-16.sch]
2020-09-19 Updated gerbers
    [rocketboard-16-B_Cu.gbr, rocketboard-16-B_Mask.gbr, rocketboard-16-B_Paste.gbr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]
2020-09-23 Added hubble, iss, and spacewalk graphics to sch/pcb
    [rocketboard-16.kicad_pcb, rocketboard-16.sch]
2020-09-23 Updated schematic plot
2020-09-23 Generated gerbers/drill files
    [rocketboard-16-B_Cu.gbr, rocketboard-16-B_Mask.gbr, rocketboard-16-B_Paste.gbr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]
2020-09-23 Added JLC text for JLC's part number to the schematic
    [rocketboard-16.sch]
2020-09-23 Removed JLC text (will pay the $1.50 to not have it on board)
    [rocketboard-16.sch]
2020-09-23 Added LCSC specific BOM, added the backup shadow excel sheet to gitignore
    [LCSC_Bom.xlsx]
2020-09-23 Updated the USB-C footprint to match the LCSC USB-C connector that works best (>1mm mounting pins)
    [rocketboard-16.sch]
2020-09-23 Changed the USB type C connector for one that fits the footprint of the LCSC part - had to adjust clearance on some pins for DRC and re-route some connections
    [rocketboard-16.kicad_pcb, rocketboard-16.sch]
2020-09-23 Regenerated gerbers/drill files
    [rocketboard-16-B_Cu.gbr, rocketboard-16-B_Mask.gbr, rocketboard-16-B_Paste.gbr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]
2020-09-23 Re-plotted schematic
2020-09-25 Updated BOMs for alternate part so that it doesn't need backordered from LCSC
    [LCSC_Bom.xlsx, bom_manual.xlsx]
2020-09-25 Added in a level shifting circuit for the LED signal (needs 5v sig, not 3.3v), added a 10uf cap on the 5v line for smoothing out possible spikey power draw from LEDs, and added test points on +5v, VC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
    [rocketboard-16.kicad_pcb, rocketboard-16.sch]
2020-09-25 Updated schematic
2020-09-25 Updated BOMs to reflect changes
    [LCSC_Bom.xlsx, bom_manual.xlsx]
2020-09-25 Updated BOMs (to fix some duplicate items issues) and added a cost spreadsheet to keep up with the cost of the prototype design
    [LCSC_Bom.xlsx, Prototype_cost.xlsx, bom_manual.xlsx]
2020-09-25 Updated design to include 10k resistors between boot select jumpers and MCU
    [rocketboard-16.kicad_pcb, rocketboard-16.sch]
2020-09-25 Updated schematic PDF
2020-09-25 Updated all dates and then updated gerbers/pdfs
    [rocketboard-16-B_Cu.gbr, rocketboard-16-B_Mask.gbr, rocketboard-16-B_Paste.gbr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]
2020-09-25 Updated boms with another alternate part, 0.1uf resistors were OOS
    [LCSC_Bom.xlsx, bom_manual.xlsx, rocketboard-16.kicad_pcb]
2020-09-28 Updated prototype costs after ordering most parts, still lacking rotary encoder knobs, and minor updates to PCB that didn't get committed before
    [Prototype_cost.xlsx, rocketboard-16.kicad_pcb]
2021-12-10 Remove unnecessary folder of symbols/footprints
2021-12-10 Update bom_manual.xlsx
    Old change that never made it to GH
    [bom_manual.xlsx]
